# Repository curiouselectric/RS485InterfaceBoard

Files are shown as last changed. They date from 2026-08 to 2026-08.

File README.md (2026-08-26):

# RS485 Sensor Interface Board

A unit to interface various RS485 sensors with a simple serial interface via an ATMega328-based circuit. The unit also provides averaged data, controlled stepped-up supply voltage and a field-adjustable ID.

"Why do you need that?", you ask.... 

I had been wanting to use an industrial soil mositure sensor for a simple project. This device was only available as an RS3485 device. So I ordered that - it then took days of head scratching to sort basic communication with the device. This unit is meant to simplify reading of avaeraged data from RS485 sensors and make it easy to get that data into your project via a simple serial request/reply set of commands.

The other issue with a lot of the RS485 sensor is that they need higher voltages supplied (such as 12V or even 24V DC). So on this interface board I added a DC-DC step up converter to power the sensor. 

I was also concerned with energy consumption (my project was battery based). If I was to leave the DC-DC converter running all the time then my battery would run down very quickly. So I added control of the power to the sensor, so that I can power up, take the readings then power down. This saves a huge ammount of energy (well, proportional to my battery size).

## Overview

The problem with measuring sensors with values that change relatively quickly is that they constantly need to be checked. This requires a bit of microcontroller time and processing. This unit is designed to solve that.

Wire up your RS485 sensor. Power the unit up. Then it will save the averaged data for you. You can then get hold of the data through serial requests and process as you need.

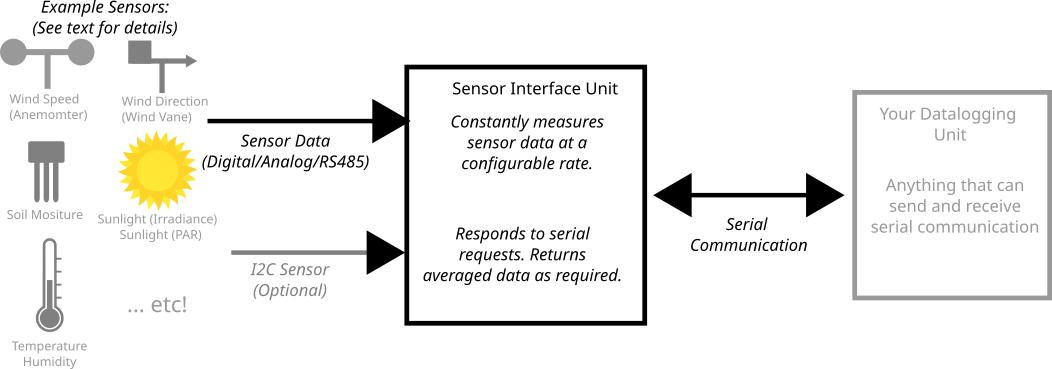
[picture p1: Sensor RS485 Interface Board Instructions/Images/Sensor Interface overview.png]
Overview


I wrote this to interface to an ESP32 data logger, which sleeps most of the time. It wakes up, talks to the RS485 sensor, gets the data it needs, then goes back to sleep, knowing the RS485 Interface Board is always monitoring.

It was designed as a relatively simple interface to remove the need for monitoring pulses/dealing with RS485 requests/getting sensor data and averaging the sensor data.

The brilliant [ESPHome project](https://esphome.io/components/#environmental) has loads of sensor types you can interafce easily with a low cost ESP microcontrollers. For systems that have WiFi and good power connections then that project is a good resource to use. This project is designed for very low power systems (battery based datalogging) and for situations where easy access to Wi-Fi is not available.

# RS485 Sensor Interface Firmware

The firmware for this project has been moved to: 

[https://github.com/curiouselectric/SensorInterfaceBoard/tree/main/Sensor%20Interface%20Board%20Firmware](https://github.com/curiouselectric/SensorInterfaceBoard/tree/main/Sensor%20Interface%20Board%20Firmware)

This is within the Sensor Interface Board repository: [https://github.com/curiouselectric/SensorInterfaceBoard](https://github.com/curiouselectric/SensorInterfaceBoard)

I have done this to keep all the sensor boards up to date with just one set of firmware for all the sensor boards.

# Hardware

A number of PCBs have been designed in KiCAD. This repository holds the RS485 sensor and is available here. A small PCB has been designed.

There is one reset switch, one user input switch and one LED output. 

There is a step-up DC-DC converter with power control (to power higher voltage sensors). 

There is a TTL to RS485 converter (to connect to the RS485 sensors)

There is a 4 pin 'Grove'-type connector for direct connection I2C (code for this is not yet implemented) 

## Board ID Number

Each unit can have a unique ID (using a push link 6 pin pad for 0-7 values), so multiple units can be added to a serial bus, if needed. The defalt is 0 (no links used).

## PCB User Switch and User LED

There is one user switch and one user LED on the unit.

The LED will show a regular flash every 5 seconds. This will briefly flash once every 5 seconds if the unit is in 'Response' mode. The LED will briefly flash twice every 5 seconds if the unit is in 'Broadcast' mode. Data will be sent at the broadcast rate.

The LED will also flash whenever data is sent of the serial port. The LED will go on before data sent and then off after data is sent.

Pressing the user switch for >0.5 seconds and then releasing will result in a switch press.

A switch press will increment the mode from 0-1-2-3-4-5 then back to 0.

The unit will flash after a button press to indicate the broadcast mode (so 0 flashes if the value is 0, 1 flash if the value is 1 etc).

If this is set to 5 then the unit works in 'Response' mode.

If this is set to 0-4 then the unit is in 'Broadcast' mode and will send the data at the relevant interval (0 = 1s, 1 = 10s, 2 = 1 min, 3 = 10 min and 4 = 1 hour).

The mode can also be set with a serial request, using the "Set the unit to broadcast:" method (see below).

# Serial Data and Commands

It returns the average values and information when requested on serial port.

If the 8-bit CRC (Cyclic Redundancy Check) is used then each request must have a 2 char CRC added between the ? and # within these commands (labelled ^^ here).
For the responses, if no CRC enabled then the ?^^ within these commands is NOT returned. You must use the ? for a command, but the response will not contain it.

At all other times then the unit is asleep.

## Set the unit to broadcast:

Request: "aaI0SEND*?^^#" where * is an int (0)= 1s data, (1)= 10s data, (2)= 60s/1 min data, (3)= 600s/10 min data, (4)= 3600s/1hr data, (5)= NO data

Returns: "aaI0SEND*?^^#" + CRC if requested where * is an int (0)= 1s data, (1)= 10s data, (2)= 60s/1 min data, (3)= 600s/10 min data, (4)= 3600s/1hr data, (5)= NO data

You can also set the unit to broadcast using the user switch. Press the button for around 0.5s or more then release. This will go through the boradcast modes from 0-1-2-3-4-5 then back round to 0. The LED will flash the number of times for the setting (so send = 0 the unit will not flash, but data will appear within 1 second!).

If the unit is in broadcast mode then the minimum and maximum wind speeds and the wind vane data are all reset each time period.

## What is baud rate?:

Request: "aaI0STBD?#" ("aaI0BD?dc#" with CRC)

Returns: "aI0CHBD9600?^^#"  // Where 9600 is the baud rate 

## Set Baud Rate:

Request: "aaI0STBD\*?^^#"  Where \* is (0)1200, (1)2400, (2)9600, (3)57600, (4)115200

Returns: "aaI0BD9600?^^#"   // Where 9600 is the baud rate + CRC if requested

## What is ID?:

Mentioned at start up of unit - it is hardware set... and cannot be changed in code.

ID selection is by using a shorting link on the pads labelled 1, 2 and 4. The default is for no pads to be connected and the ID is 0. This means the unit will respond to "I0" as the ID.

To change the ID to another number from 0-7 then use a shorting link on the pins to create a binay number. The connections are:

1    |2    |4     | ID
-------|-------|-------|----
NC     |NC     |NC     | 0
CONN |NC     |NC     | 1
NC     |CONN |NC     | 2
CONN |CONN |NC     | 3
NC     |NC     |CONN | 4
CONN |NC     |CONN | 5
NC     |CONN |CONN | 6
CONN |CONN |CONN | 7

You can request the ID:

Request: "aaI*ID?^^#"  The * value can be anything.

Returns: "aaIXID:X?^^#"   // Where X is the device ID + CRC if requested

## Request Data from ONE channel

Request: “aaI0R00A*?^^#” where 00 is the channel number (00, 01 etc) and * is the averaging period (* = 0 for 1 sec data, 1 for 10 sec data, 2 for 60 sec (1 min) data, 3 for 600 sec (10 min) data and 4 for 3600 sec (1 hr) data 

Returns:  "aaI0R00A*:123.40:123.40:123.40?^^#"  // This wil return the average data then : then the minimum value then : then the maxximum value.

## Request Data from ALL channels

Request: “aaI0RAAA3?^^#”

Returns: "aaI0RAAA1:123.40:567.80?^^#" where the first item of data is channel 0, the next is channel 1. This will depend upon the number of channels.

## Request ALL Minimum data

Request: “aaI0RMNA4?^^#”  - does not matter what averaging period. min/max are just the min/max seen at max data rate.

Returns: "aaI0RMN:123.40:567.80?^^#"  where the first item of data is channel 0, the next is channel 1. This will depend upon the number of channels.

## Request ALL Maximum data

Request: “aaI0RMXA0?^^#”  - does not matter what averaging period. min/max are just the min/max seen at max data rate.

Returns: "aaI0RMX:123.40:567.80?^^#"  where the first item of data is channel 0, the next is channel 1. This will depend upon the number of channels.

## Reset the Min and Max value:

The min and max of each channel are logged. These are reset if the data is sent in broadcast mode. If the unit is in Response mode then you need to reset the min/max when you have taken the data.

Request: "aaI0RESET?#" ("aaI0RESET?d9#" with CRC)

Returns: "aaI0RSTOK#"

## Request Temperature, Humidity and Pressure Data

This command can only be used if the I2C AHT20/BMP280 sensor is attached and has been defined in the code. Otherwise it will return an error.

You can call this at any time and the unit will request from the sensor. It is NOT averaged or requested at any other point.

The Temp and Humidity board is an AHT20 (with device ID 0x38) and a BMP280 is used to measure the air pressure (with device ID 0x77).

Request: "aaI0TEMP?^^#"  (^^ for the CRC)

Returns: "aaI0T$$.$$H$$.$P$$$$$$?^^#" (^^ for the CRC) and $$$ are the values (floats) for Temeprature in C and Reltive Humidity in % and Air Pressure in Pa.
Returns: "aaI0T-H-P-#" if the board is not connected or there is an issue wth one of the sensors.

## Serial 'Button' press

You can simulate a button press with a serial command. This might be useful for some logging applications

The command "aaI0SWA?^^#"  (Where ^^ is the CRC of the data before the ?) will act just like a button press. This is for control via a data logger serial port without access to the physical switch.

Request: "aaI0SWA?^^#" 

Returns: "aaSEND*?^^#", where * is the time interval to send data (0->1->2->3->4->5->0 etc, with 5 never sending)

## What is the software version?:

Request: "aaI0SWV?^^#"

Returns: "aaI0SWV:1.0?^^#" (where 1.0 is the software version)

## What is the device type?:

Request: "aaI0DT?^^#""

Returns: "aaI0DT:SM?^^#" where SM is the device type (SM = Soil Moisture) - check the sensor list for these 2 char codes.

## Add CRC check:

Within the config of the firmware a CRC (Cyclic Redundancy Check) can be added to the data (or not!).

Set this true using the flag in the config.h file:

  #define ADD\_CRC\_CHECK     true    // Use this to add CRC check to incomming and outgoing messages
  
This uses the CRC routines from Rob Tillaart, available here: https://github.com/RobTillaart/CRC

A 'CRC-8/SMBUS' is perfromed on the data and a 2 byte CRC code is added to all replys (and expected on all enquiries). This is added between a ? and # symbol.

If no CRC then the end char is a #.

For example: aaI0RESET?d9# has the CRC check d9 added to the reset request.

Remember: Capitalisation will affect the results: D is not the same as d!

You can use this online calculator to check your CRC: https://crccalc.com/ The type of CRC is CRC-8/SMBUS.

## Failure codes:

If data is not that length or does not have 'aa' and '#' at start/end then return with send "aaFAIL\*\*#" error code. All will have CRC on these codes, if requested.

+  "aaFAILCRC?^^#": CRC check fail
+  "aaFAILTL?^^#": String too long
+  "aaFAILID?^^#": Problem with ID
+  "aaFAILIDX?^^#": ID not correct to device
+  "aaFAILPE?^^#": No aa and # on the string
+  "aaFAILBD?^^#": Baud rate change fail
+  "aaFAILCN?^^#": Channel number requested is greater than channels existing
+  "aaFAILCMD?^^#": Command not recognised 

# Sensor Specific Commands
For each sensor type there are additional commands. These are only available if the correct firmware has been installed.
They are listed here.

## 'SM' RS485 Soil Moisture Sensor

There are no extra commands.
Soil Moisture (% (m3 water in m3 soil)) and Soil Temperature (C) are monitored.

## 'PY' RS485 Pyranometer Irradiance Sensor

There are no extra commands.
Irradiance (in W/m2) is monitored.

## 'DC' RS485 DC Power Sensor

There are no extra commands.
Voltage (V), Current (A), Power (W) and cumulative Energy (Wh) are monitored.

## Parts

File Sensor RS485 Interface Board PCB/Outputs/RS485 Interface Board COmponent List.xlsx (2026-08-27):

Id | Designator | Footprint | Quantity | Designation | Supplier and ref | Column1 | _1
1 | C1, C3, C4 | C1_wide_lg_pad_2 | 3 | 100n
2 | C2 | C_Radial_D6.3_L11.2_P2.5 | 1 | 100u
3 | C5, C6 | C1_lg_pad | 2 | 22p
4 | D1 | TH_LED-5MM_AK | 1 | LED
5 | DCDC1 | TH_DCDC_Step_up_MT3608 | 1 | DC-DC_GENERIC
6 | J1 | SIL-3_lg_pad_PWR_SELECT | 1 | PWR SEL
7 | P1 | SIL-4_Grove_SCREW | 1 | SERIAL
8 | P2 | RS485 Logo Design | 1 | LOGO2
9 | P3 | PCB_outline_JSL22L | 1 | PCB
10 | P5 | SIL-4_Grove_Labelled_Correct | 1 | I2C
11 | P6 | SIL-4_Grove_SCREW | 1 | RS485
12 | P7 | ID_SELECT_3x2 | 1 | BOARD ID
13 | P8 | TH_6x1_FTDI | 1 | PROG
14 | P9 | ISP_3x2 | 1 | ISP
15 | P10 | TCEC_Words_13mm | 1 | LOGO3
16 | P11 | 2019_011_16_CuriousElectricCompany_Logo_Round_Logo_No_words_KiCAD_10mm_PCBLogo | 1 | LOGO2
17 | Q1 | TO-92_Inline | 1 | 2N3904
18 | Q2 | TO-251-3_Vertical | 1 | IRFR9220
19 | R1 | TH_Resistor_1 | 1 | 1k
20 | R2, R3 | TH_Resistor_1 | 2 | 100k
21 | R4 | TH_Resistor_1 | 1 | 470
22 | R5 | TH_Resistor_1 | 1 | 10k
23 | R6, R7 | TH_Resistor_1 | 2 | 4k7
24 | SW1 | TH_FRONT_SW | 1 | SWA
25 | SW2 | TH_FRONT_SW | 1 | RST
26 | U1 | TH_RS485_BI_SERIAL | 1 | RS485_TTL_Module
27 | U2 | DIP-28_W7.62mm | 1 | ATmega328P-P
28 | Y1 | Crystal_HC49-4H_Vertical | 1 | 8MHz_XTAL

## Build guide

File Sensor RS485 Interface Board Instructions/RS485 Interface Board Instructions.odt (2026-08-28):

| RS485 Sensor Interface Board Kit Instructions

Date: | 26/8/2026 | Version: | 1.0 | By: | Matt Little

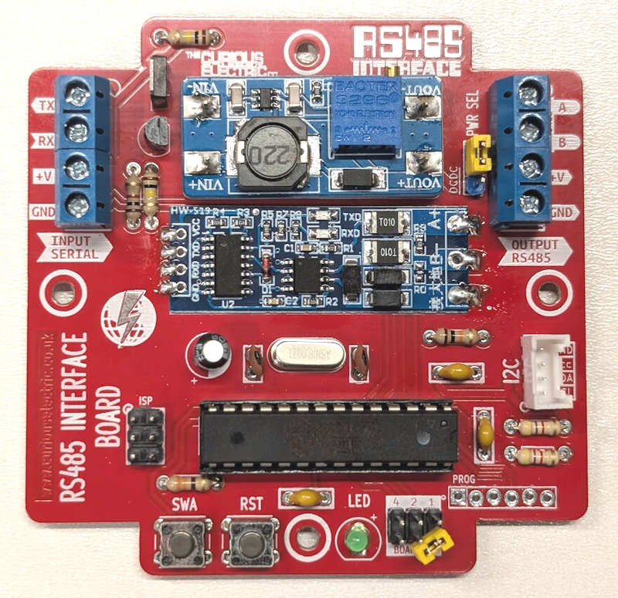
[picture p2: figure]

This circuit adds an RS485 interface to an ATMEGA328 to connect to different RS485 sensors and provide averaged data via a UART interface. It is designed to be easy to use, provide correct voltage levels and be energy efficient.

Note: It requires another micro-controller unit to request and store the data from the sensor interface board.

You must upload the correct firmware for your sensor, please check the github for examples:

https://github.com/curiouselectric/SensorInterfaceBoard

It provides a more easy to use UART serial interface to obtain averaged data the sensor. Data can be 1s,10s, 1min, 10min and 1hr averaged data along with the maximum and minimum values within that time period.

It also provides a controlled step-up converter (if needed) to power the attached sensor, which can step up the supply voltage (3.3V or 5V DC) to the voltage required by the sensor, such as 12V or 24V. This can be switched off between sensor reads to save energy from the battery.

There is also an I2C interface to add additional sensors, such as a temperature or humidity.

# Parts included:

| 1 x Grove socket | 2 x 2 way headers 1 x 3 way header | 2 x 3x2 Header Pins | | 2 x Jumpers | | IFRF9220

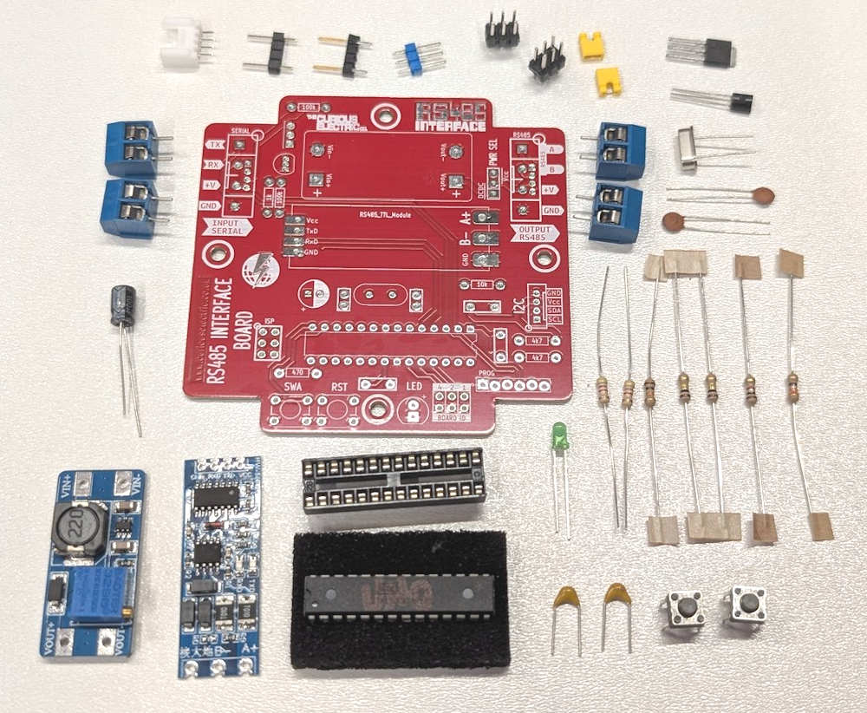
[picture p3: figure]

| | | | | | | 2N3904
| | | | | | | 16MHz crystal
2 x 2 way screw terminals | | | | | | | 2 x 2 way screw terminals
| | | | | | | 2 x 22pf Capacitor
100uf Capacitor
PCB | | | | | | | 7 x Resistors
DC-DC Converter | RS485-TTL Module | ATMEGA328 and IC holder | | 3 x 100nf Capacitor (2 shown!) | | LED | 2 x Switches

# Parts list:

Item | Ref | Quantity | Item | Ref | Quantity
PCB | | 1 | Resistor - 1k | R1 | 1
Capacitor – 100nf | C1, C3, C4 | 3 | Resistor - 100k | R2, R3 | 2
Capacitor – 100uf | C2 | 1 | Resistor - 470 | R4 | 1
Capacitor – 22pf | C5, C6 | 2 | Resistor - 10k | R5 | 1
Green LED | D1 | 1 | Resistor - 4k7 | R6, R7 | 2
DC-DC Converter | DCDC1 | 1 | Tactile switch | SW1, SW2 | 2
3 Way Header | J1 | 1 | RS485 – TTL Module | U1 | 1
Grove connector 4 pin | P5 | 1 | Modified 4 way headers with 2 pins | For U1 | 2
2 Way Screw Connector (2 for each) | P1, P6 | 4 | 28 Pin IC DIP Holder | U2 | 1
3x2 Header | P7, P9 | 2 | ATMEGA328P 28pin | For U2 | 1
Transistor – NPN, 2N3904 | Q1 | 1 | 16MHz Crystal | Y1 | 1
Transistor – N-FET, IFRF9220 | Q2 | 1 | Jumpers | | 2

# Tools required (not supplied):

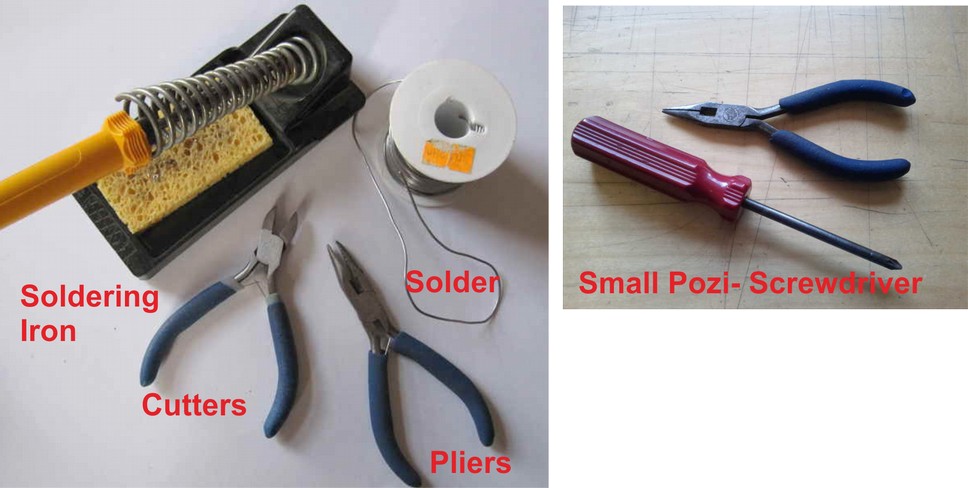
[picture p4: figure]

| | Long-nosed Pliers
Soldering Iron | | Posi-drive and flat-head Screwdriver
Solder
Side cutters

Additional Items

- USB to 6 way ‘FTDI’ style serial converter:
  - Search for “FT232RL USB to TTL Mini USB Port FTDI Serial Adapter Module for Arduino 5V/3.3V” on eBay
  - Or this FTDI 3.3V one: https://ftdichip.com/products/ttl-232r-3v3/
  - Or this FTDI 5V one: https://ftdichip.com/products/ttl-232r-5v/
  - You can also use an Arduino as a USB to serial converter.
- To update/change code:
  - Computer with Arduino IDE and additional libraries installed. (See github repository for the Sensor Interface Software for more details: https://github.com/curiouselectric/SensorInterfaceFirmware ).

# Device & Wiring Overview:

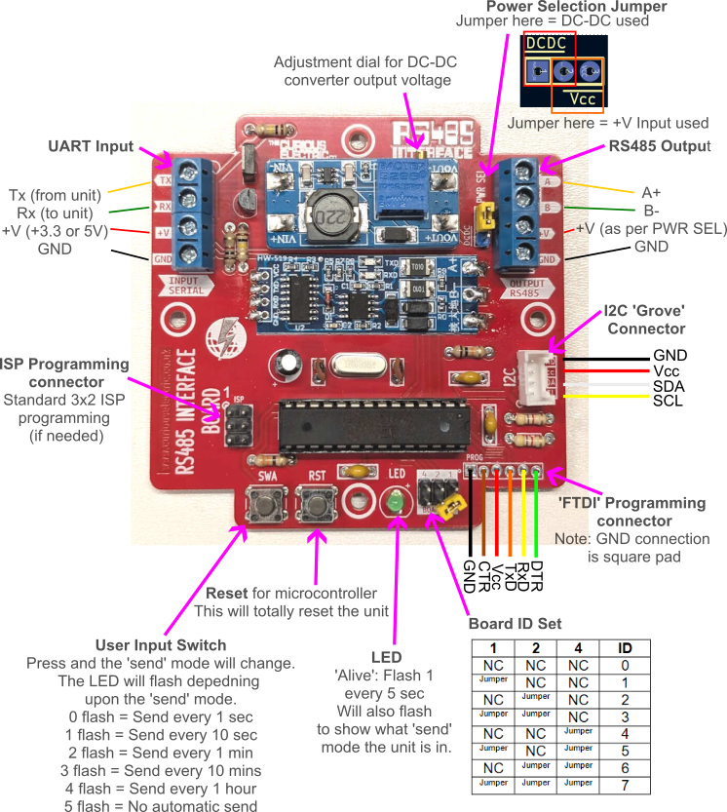
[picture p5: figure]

Instructions:

Step: 1 | Add resistors

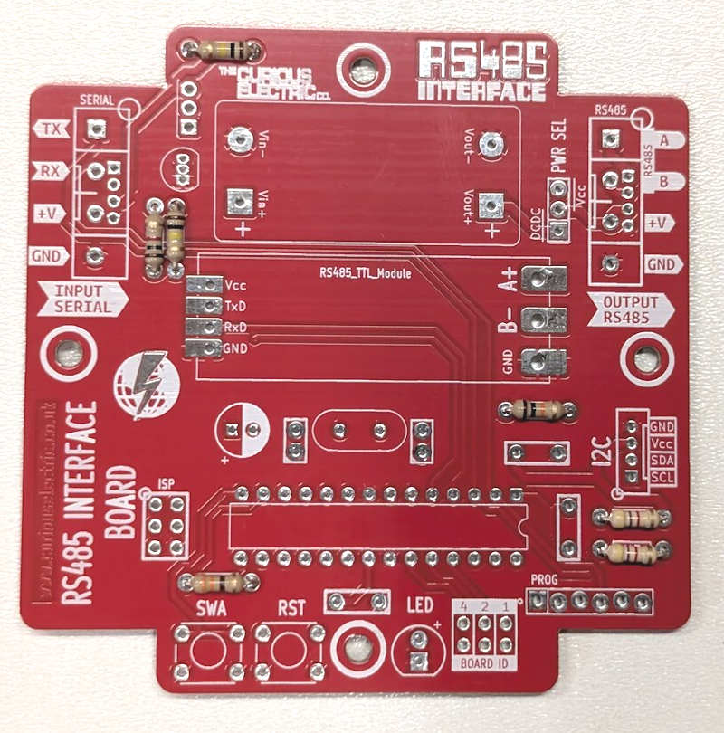
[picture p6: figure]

| | Value Ref Colour 1k R1 Brown, Black, Red, Gold 100k R2, R3 Brown, Black, Yellow, Gold 470 R4 Yellow, Violet, Brown, Gold 10k R5 Brown, Black, Orange, Gold 4k7 R6, R7 Yellow, Violet, Red, Gold Insert and solder the resistors. Polarity does not matter for resistors. Ensure they are soldered flat close to the PCB. Use a multimeter or colour code chart to ensure correct resistor values.

Step: 2 | Add capacitors

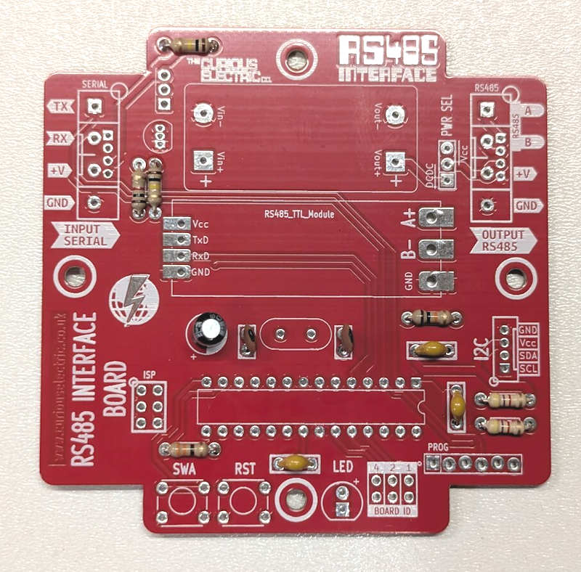
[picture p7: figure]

| | First solder the non-polarised capacitors. Orientation of these does not matter: Value Ref Marking 100nf C1, C3, C4 104 (brown blob) 22pf C5, C6 22(orange disk) Next solder the polarised capacitor. Ensure correct orientation of this component. The negative lead is marked with a white strip. The positive lead is slightly longer than the negative. Align the positive lead with the + sign and the negative lead with the white PCB marking. Value Ref Marking 100uf C2 16V 100uf

Step: 3 | Add IC holder and crystal

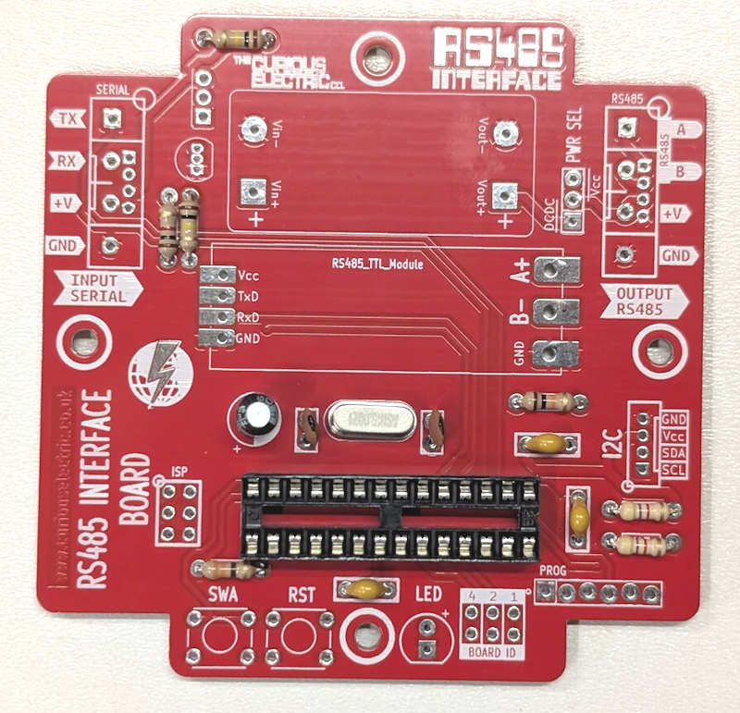
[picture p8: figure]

| | A 28-pin IC holder fits into U2 Ensure correct orientation! Ensure the notch on the holder aligns with the notch shown on the PCB. The silver crystal is soldered into the area marked Y1. Orientation does not matter.

Step: 4 | Add Switches and LED

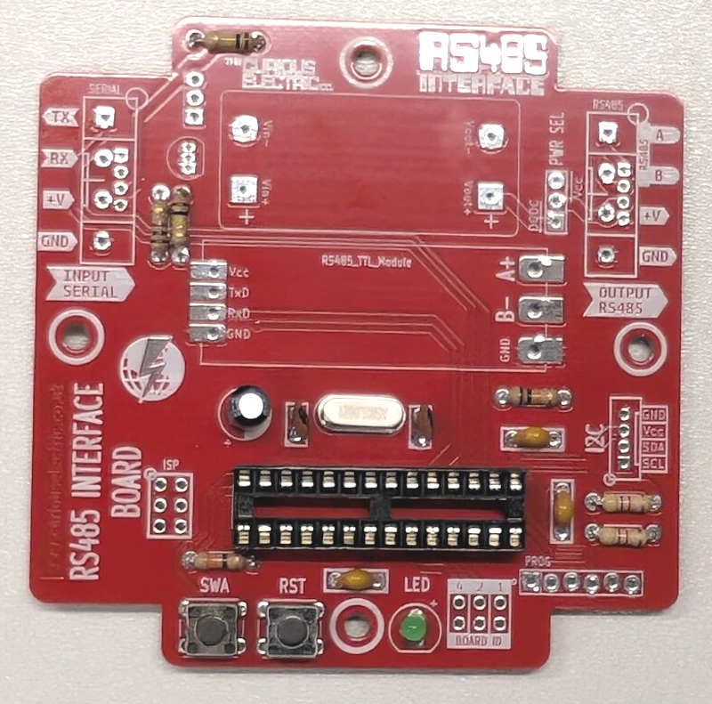
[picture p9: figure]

| | Solder the two push switches into the areas marked SW1 (“SWA”) and SW2 (“RST”). They can only fit in the correct orientation. Ensure correct orientation for the LED, D1. Solder the LED into D1. The long lead is positive, so place that into the hole marked +. The negative side is slightly flat.

Step: 5 | Add transistors

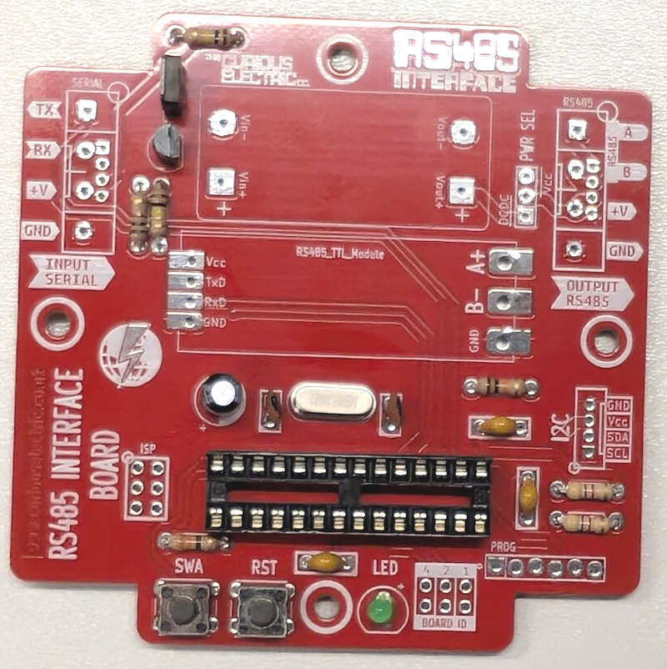
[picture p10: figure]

| | Solder transistors Q1 and Q2 into the correct locations. Ensure both transistors follow the markings on the PCB. There is a thicker white line showing which side the heat-sink on transistor Q2 should be aligned with.

Step: 6 | Add header pins and set ID

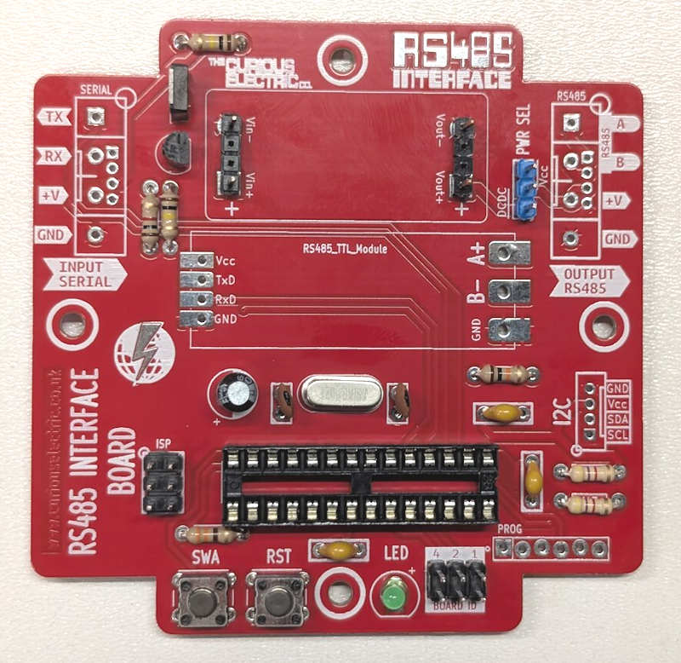
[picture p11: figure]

Use the 2 x special 2 pin headers and solder onto the pads for the DC-DC converter (DCDC1)

Use the 3x1 header pins for the “PWR SEL” area (J1). A jumper on this controls if either the sensor is powered by the supplied voltage (on the input serial terminal) OR the DC-DC converter.

Use the 2 x 3x2 header pins and put them into the areas marked P7 and P9.

P9 is an ISP (In Series Programmer) connector for uploading code onto the unit (if needed)

P7 is used to set the board ID.

You can set the ID of the unit by connecting the header pads with a jumper. The default ID is 0, with no jumper attached.

1 | 2 | 4 | ID
NC | NC | NC | 0
Jumper | NC | NC | 1
NC | Jumper | NC | 2
Jumper | Jumper | NC | 3
NC | NC | Jumper | 4
Jumper | NC | Jumper | 5
NC | Jumper | Jumper | 6
Jumper | Jumper | Jumper | 7

Step: 7 | Add RS485 module board

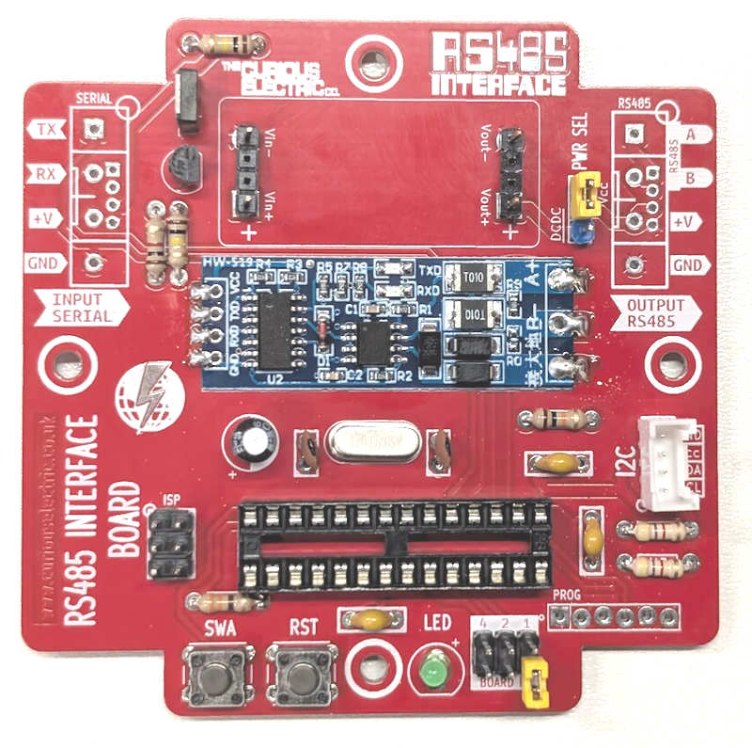
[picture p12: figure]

| | Place the RS485-TTL module flat onto the circuit board. Ensure the pads align with the castellated holes on the module board. Add a blob of solder to each of the pads (4 smaller ones on the TTL side and 3 larger ones on the RS485 side). Ensure there is enough solder to make a good connection.

Step: 8 | Add DC-DC converter module

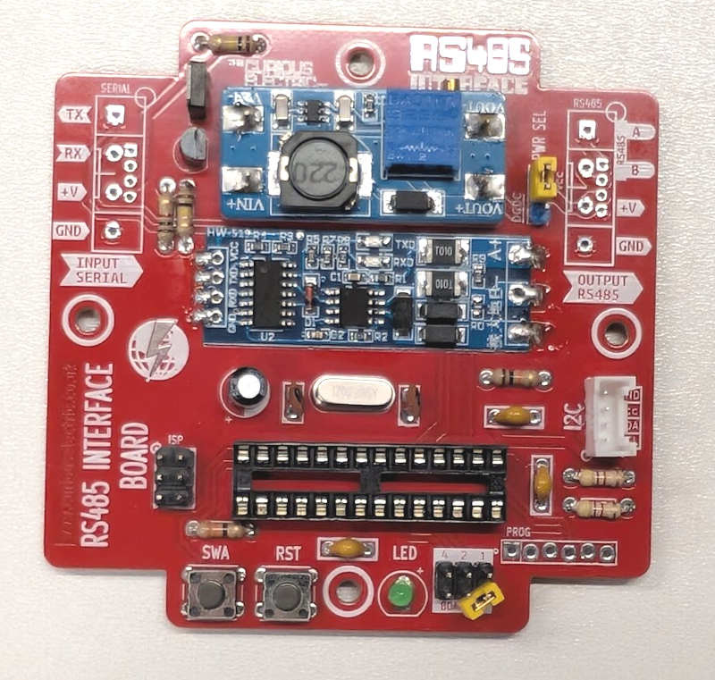
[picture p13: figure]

| | Fit the DC-DC converter module onto the header pins you soldered in step 6. Make sure this is put on the right way around. The flat side of the module should go against the main red PCB. Make sure the little brass adjustment dial is pointing to the edge of the PCB. This can be adjusted with a small flat screwdriver. It can be adjusted from 3.3V up to 30V DC. The max current is 2A, but it is advised to stay under 500mA at most. Note: Before adding your sensor you must check the output voltage is correct for your RS485 sensor. See details later in these instructions.

Step: 9 | Add screw terminals and Grove connector

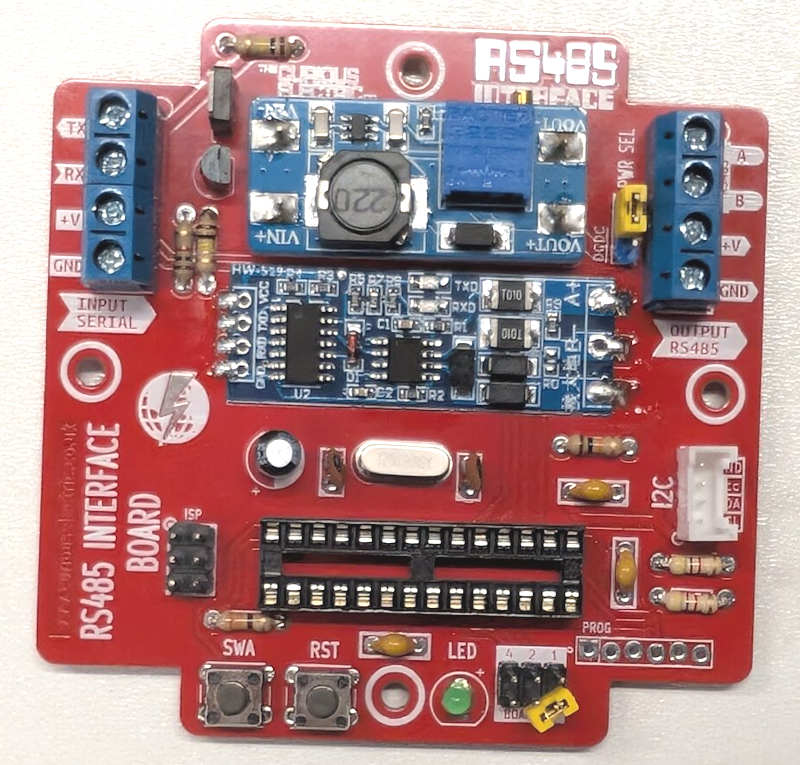
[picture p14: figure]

| | Use two of the 2-way screw terminals and slot them together to make a 4 way screw terminal unit. Do this with the two sets of 2-way screw terminals. Solder them into the areas for the INPUT (P1) and the RS485 OUTPUT (P6). Ensure the holes for the cables are face out, so cables can enter from each side. Also solder the ‘Grove’ 4 pin connector into P5. Ensure you fit this as shown, with the large notch facing to the edge of the PCB.

Step: 10 | Add microcontroller
| | You can now carefully insert the ATMEGA328 microcontroller into the IC holder. Ensure the notch on the IC matches the IC holder and the PCB! Be careful no pins are bent as you push this component in.

Step: 11 | PCB is finished!
Have a nice cup of tea.

Step: 12 | Check Device: Connect to USB-TTL Converter

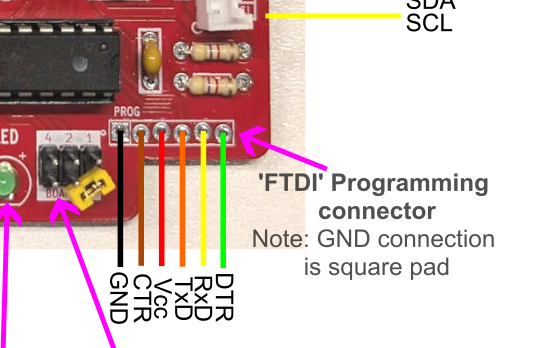
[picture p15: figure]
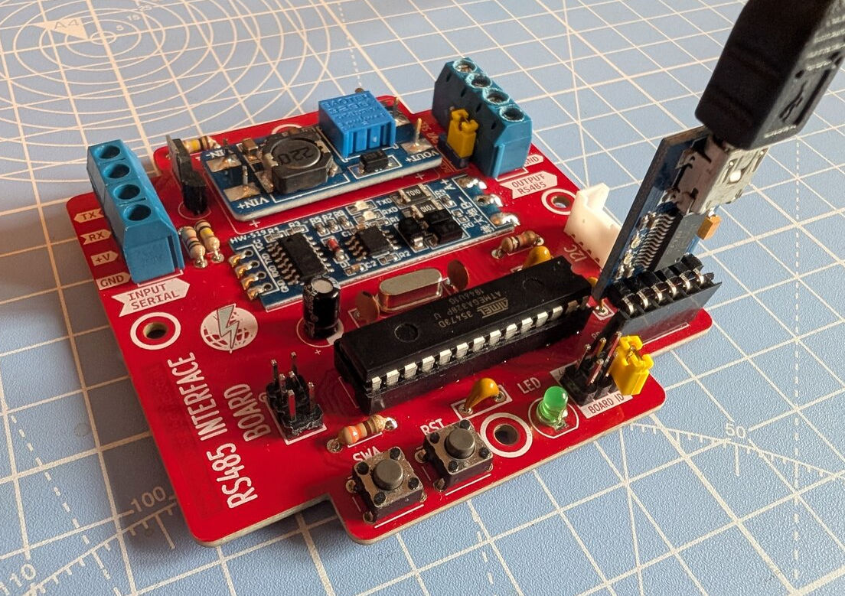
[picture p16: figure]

To program and check the microcontroller then you will need a USB to TTL converter with the ‘FTDI’ pin out. This fits into the ‘PROG’ connector. This will also power the board. You can also use a USB-TTL converter cable wired to the SERIAL INPUT terminals, but you will not be able to upload new code via that connector. If you monitor the serial port at 9600 baud then you can send and receive responses. Check that some data is being received and that the green light flashes to show the unit is working.

Step: 13 | Check DC-DC converter voltage

BEFORE you add the RS485 sensor test and double check the output voltage on the DC-DC converter.

Power up the device, either from the PROG connection OR from the “INPUT SERIAL” connections.

This will depend upon the ‘PWR SEL’ jumper, which chooses if the Serial Input +V voltage is used OR if the DC-DC converter is used.

If the DC-DC converter is used then check the output voltage with a multimeter. The voltage may jump as the power is switched, the higher voltage will be the ‘blip’ of output voltage for the sensor. This switches on and off to save energy.

This should be the same as required by your RS485 sensor.

Turn the little brass dial with a preset trimmer or small screwdriver.

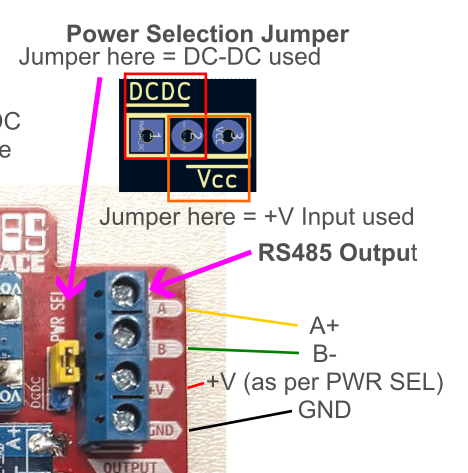
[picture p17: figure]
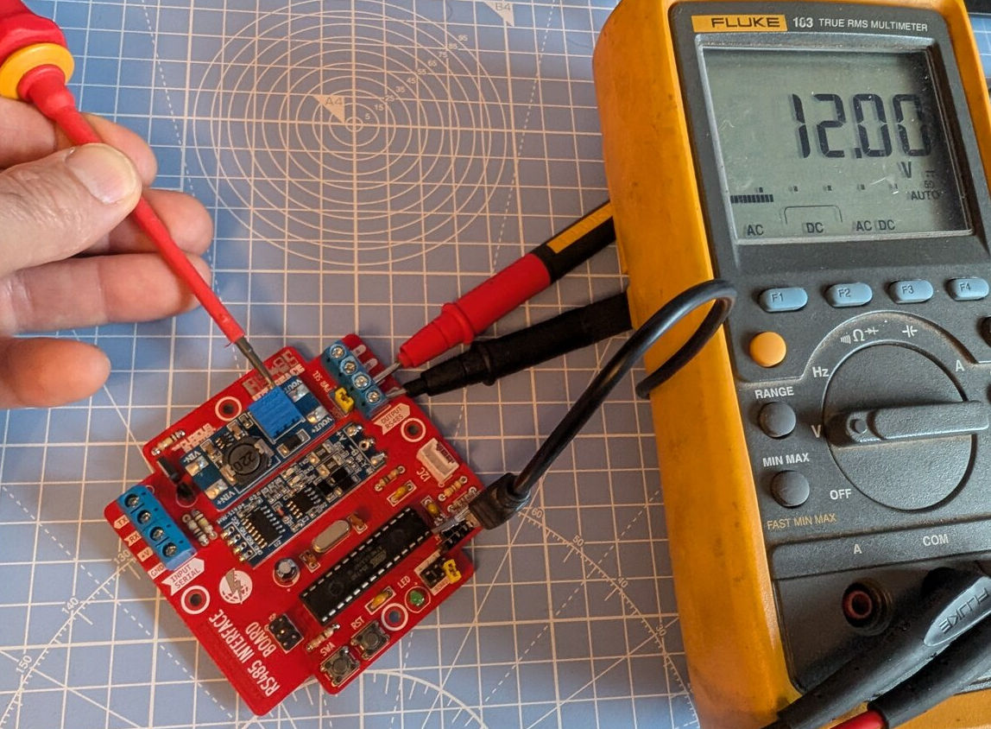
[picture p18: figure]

Step: 14 | Wire up RS485 Sensor

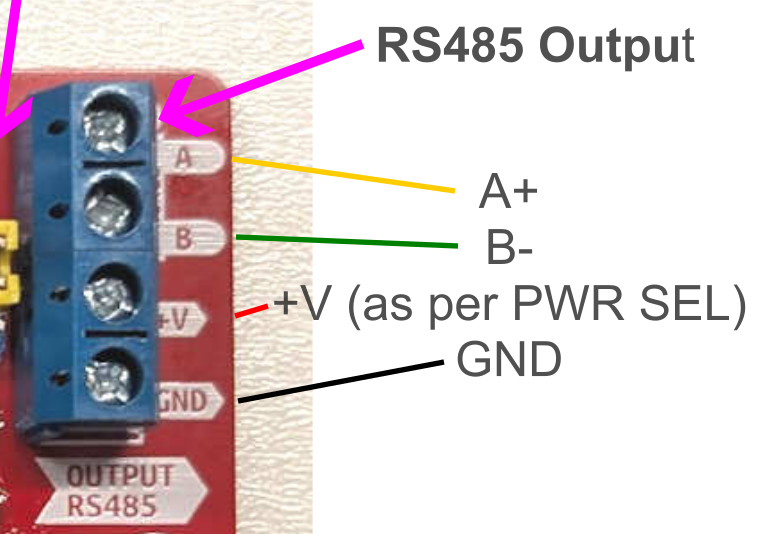
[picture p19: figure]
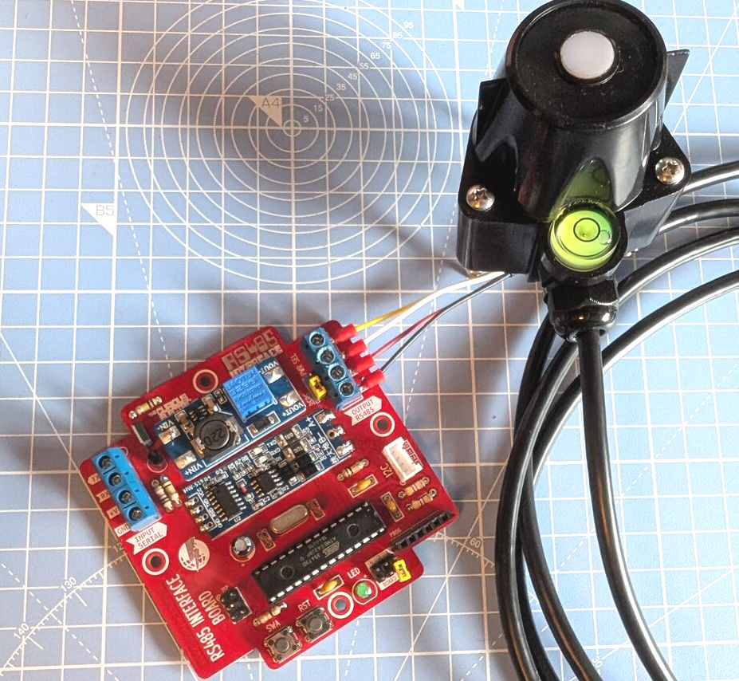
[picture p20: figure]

Now the output voltage has been set you can wire up the RS485 sensor you are using. Switch off power to the board. Wire up your sensor to the “OUTPUT RS485” terminals following the screen printed labels. In the photo shown here, a solar pyranometer has been wired up. Check your sensor data-sheet for the correct colour wires and pin out, as it may not be the same as shown here.

Step: 15 | Wire up the Serial Input to your microcontroller.

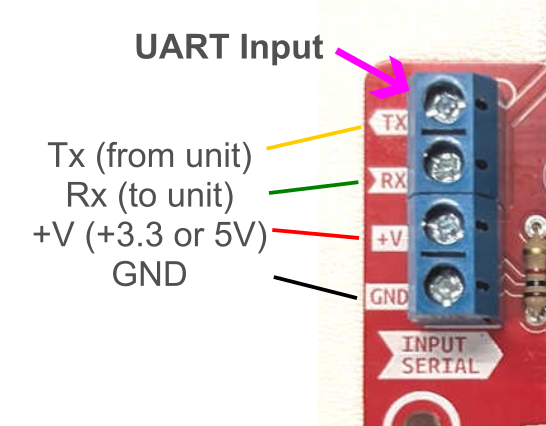
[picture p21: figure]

There is one main ‘Input Serial’ connector (sometimes called UART Input). Wire this up to your microcontroller or to a USB-TTL converter cable. Double check that Rx and Tx are correctly wired (usually Rx from the microcontroller goes to Tx of the sensor and vice-versa). Check you are getting data via the Input Serial connections.

Step: 16 | Program Device: Connect to USB-TTL Converter
Note: This step is only needed if firmware not already uploaded. To program the microcontroller then you will need a USB to TTL converter with the ‘FTDI’ pin out. If you monitor the serial port at 9600 baud then you can send and receive responses. You can also upload new firmware using the Arduino IDE. These units use the ‘MiniCore’ board manager and the IC is the “ATMEGA328” with an “External 16MHz” oscillator. Follow the github examples and information for the most up to date information regarding the serial data and the functionality of the unit.

Step: 17 | Ensure the firmware used on the unit is the correct version for your sensor!
Different firmware options are required for different RS485 sensors. This can be where the fun begins! You can alter the code and improve it as you need. Note: This step is only needed if the correct firmware has not already been uploaded. For options and firmware upload options, please see: https://github.com/curiouselectric/SensorInterfaceBoard This is kept online, so it can be easily updated.

Step: 18 | Send Serial Commands

There are many serial commands that the unit can respond to.

In normal operation the unit will start up and the LED will flash every 5 seconds to show it is alive.

If you monitor the serial port data you should see data at 1 or 10 second intervals at 9600 baud rate. This depends upon the send rate selected. Press SWA and this will roll through the 6 data send rates (which are 1second, 10 second, 60 second, 10 min, 1 hour and “no data send”). Put it into 1 second data mode and you should see data appearing every second. Check the data looks correct.

For the most recent information, please see:

https://github.com/curiouselectric/SensorInterfaceBoard

This is kept online, so it can be easily updated.

Step: 19 | Write your own code
Everyone’s application is different, so this is where things get fun for your application! You need to think about what you would like from the unit. I have set up units that send out data at regular 1 min outputs with a wireless transmitter. This used broadcast mode. I have also set up units that record the data to an SD card by using request mode.

## Design Files:

The design files for this PCB, along with these instructions, is available from the github repository for this board:

https://github.com/curiouselectric/RS485InterfaceBoard

Note: This repository is just for the design files, not the firmware. Please see links in instructions for the firmware repository.

## Contact details:

This kit has been designed and produced by:

The Curious Electric Company

hello@curiouselectric.co.uk

www.curiouselectric.co.uk

We would like you to be happy with this kit. If you are not happy for any reason, then please contact us and we will help to sort it out.

Please email hello@curiouselectric.co.uk with any questions or comments.

Please tweet us at @curiouselectric

If any parts are missing from your kit, then please email hello@curiouselectric.co.uk with details, including when and where the kit was purchased.

More technical information can be found via www.curiouselectric.co.uk

# Circuit Schematic Page 1:

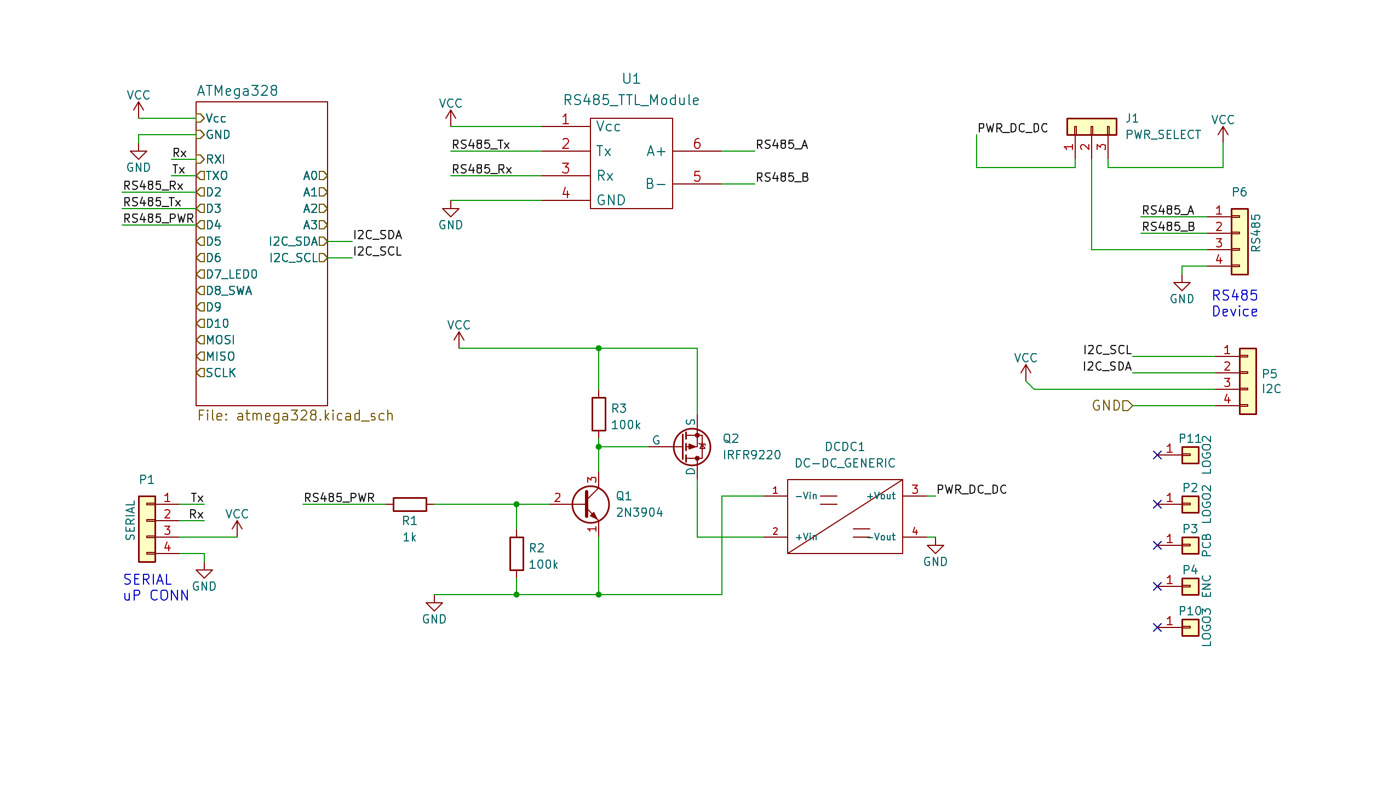
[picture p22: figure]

# Circuit Schematic Page 2:

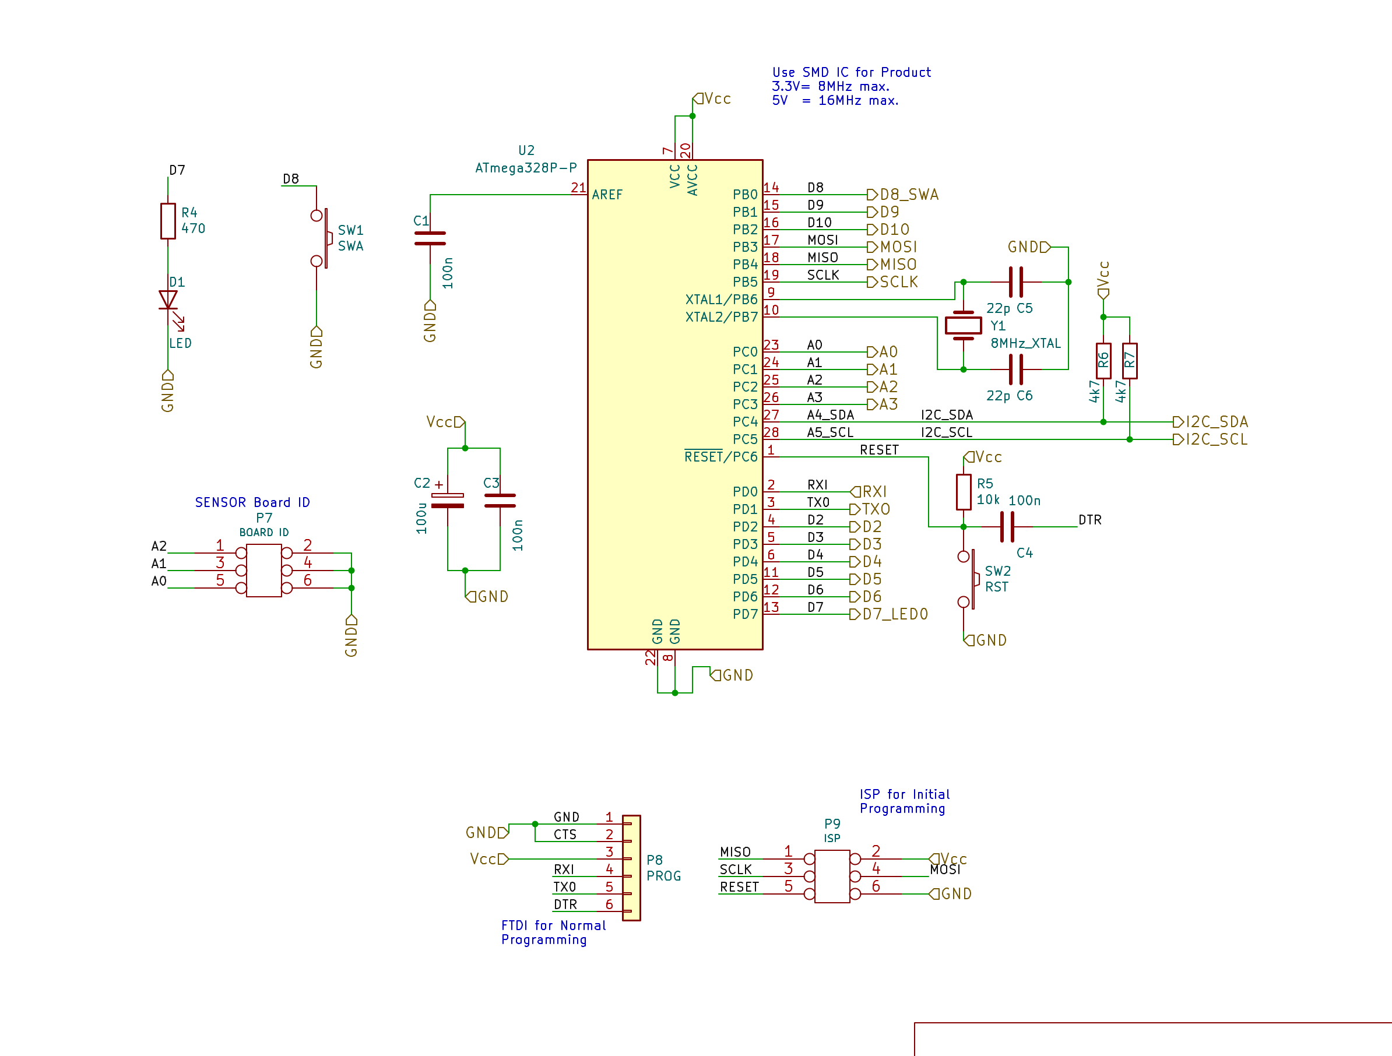
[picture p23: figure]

# PCB Design:

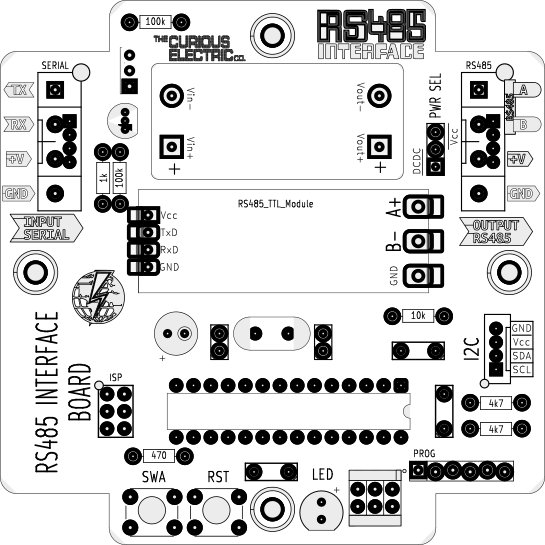
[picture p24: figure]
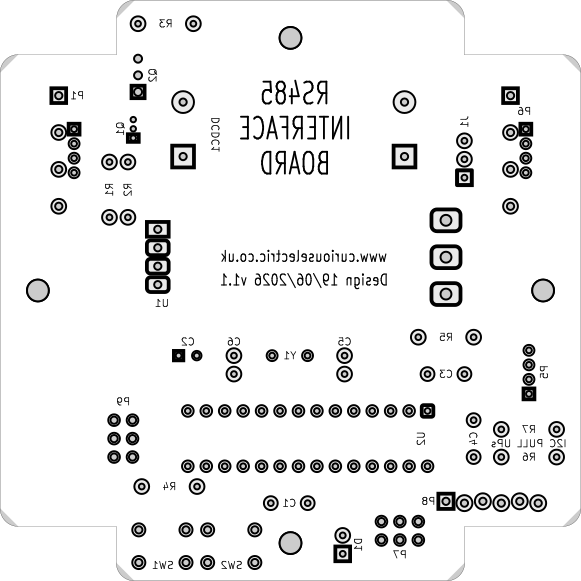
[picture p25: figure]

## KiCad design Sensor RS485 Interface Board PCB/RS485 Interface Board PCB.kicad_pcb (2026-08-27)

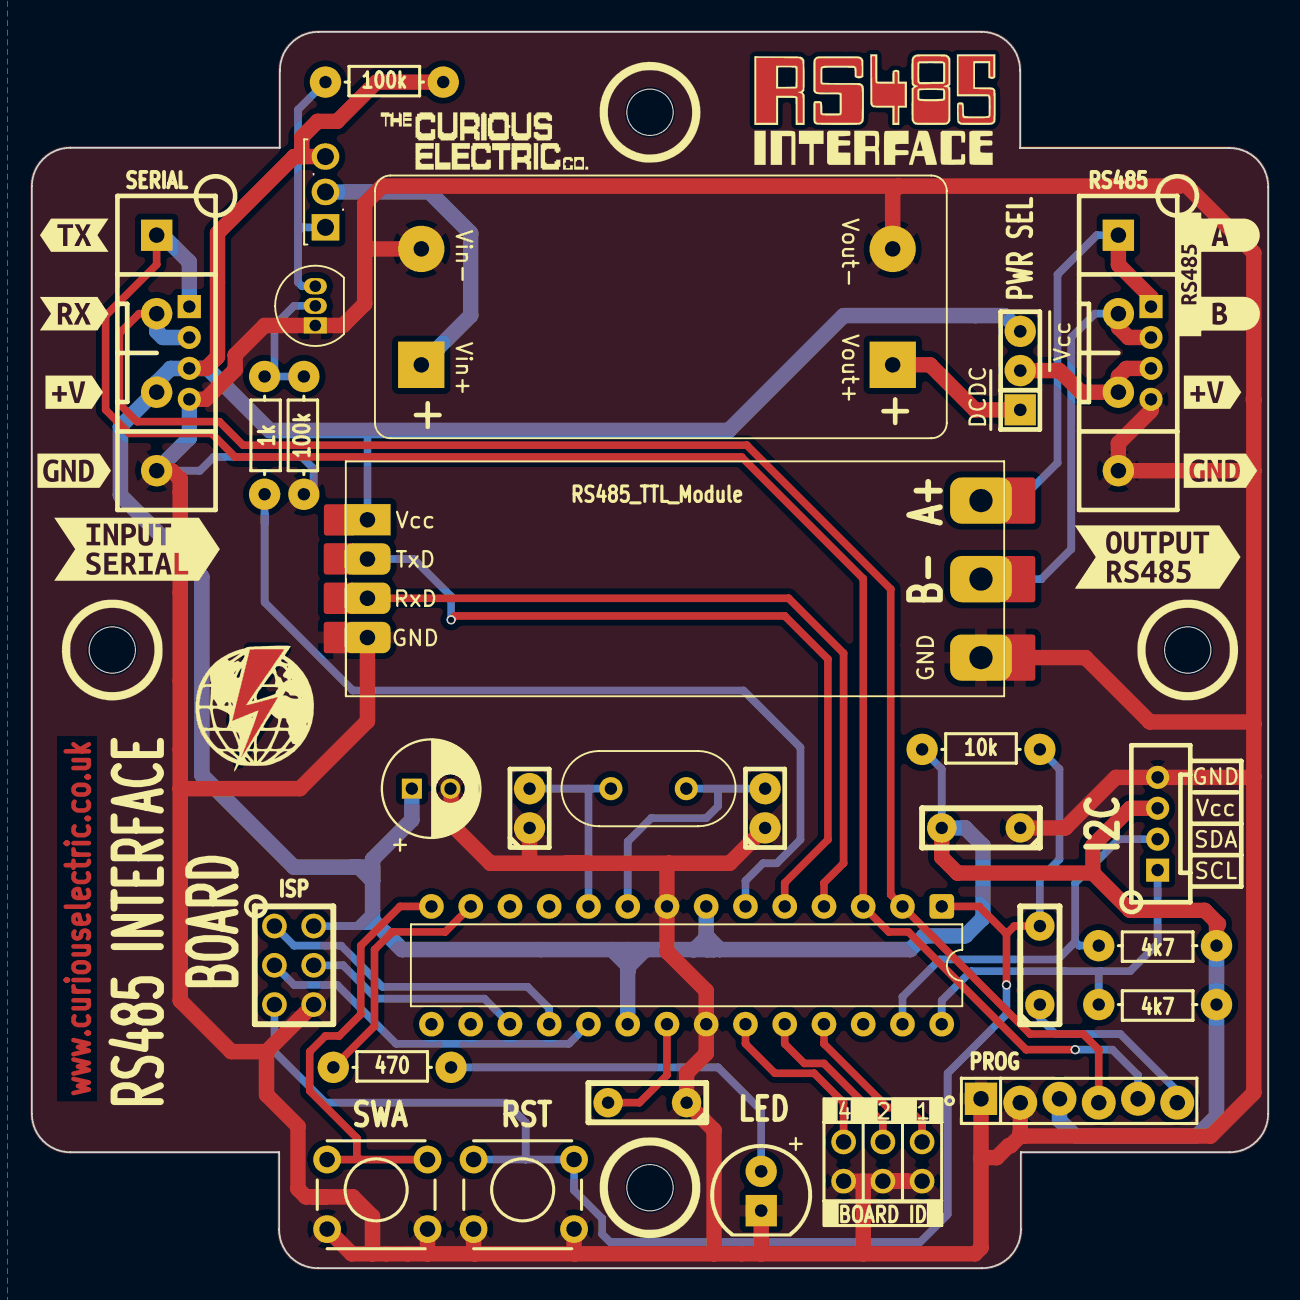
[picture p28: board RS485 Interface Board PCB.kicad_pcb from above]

Board: 2 copper layers, 80.0 x 80.0 mm, 44 parts (1 on the bottom side), 30 nets.

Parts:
C1, C3, C4: 100n; C1_wide_lg_pad_2
C2: 100u; C_Radial_D6.3_L11.2_P2.5
C5, C6: 22p; C1_lg_pad
D1: LED; TH_LED-5MM_AK
DCDC1: DC-DC_GENERIC; TH_DCDC_Step_up_MT3608
J1: PWR SEL; SIL-3_lg_pad_PWR_SELECT
P1: SERIAL; SIL-4_Grove_SCREW
P2: LOGO2; RS485 Logo Design
P3: PCB; PCB_outline_JSL22L
P5: I2C; SIL-4_Grove_Labelled_Correct
P6: RS485; SIL-4_Grove_SCREW
P7: BOARD ID; ID_SELECT_3x2
P8: PROG; TH_6x1_FTDI
P9: ISP; ISP_3x2
P10: LOGO3; TCEC_Words_13mm
P11: LOGO2; 2019_011_16_CuriousElectricCompany_Logo_Round_Logo_No_words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
Q1: 2N3904; TO-92_Inline
Q2: IRFR9220; TO-251-3_Vertical
R1: 1k; TH_Resistor_1
R2, R3: 100k; TH_Resistor_1
R4: 470; TH_Resistor_1
R5: 10k; TH_Resistor_1
R6, R7: 4k7; TH_Resistor_1
SW1: SWA; TH_FRONT_SW
SW2: RST; TH_FRONT_SW
U1: RS485_TTL_Module; TH_RS485_BI_SERIAL
U2: ATmega328P-P; DIP-28_W7.62mm
Y1: 8MHz_XTAL; Crystal_HC49-4H_Vertical
kibuzzard-68D6B9BB: G***; kibuzzard-68D6B9BB
kibuzzard-68D6B9C5: G***; kibuzzard-68D6B9C5
kibuzzard-68D6B99D: G***; kibuzzard-68D6B99D
kibuzzard-68D6B914: G***; kibuzzard-68D6B914
kibuzzard-68D6B946: G***; kibuzzard-68D6B946
kibuzzard-68D6B980: G***; kibuzzard-68D6B980
kibuzzard-68D6BA3C: G***; kibuzzard-68D6BA3C
kibuzzard-68D6BA4A: G***; kibuzzard-68D6BA4A
kibuzzard-68D6BA8E: G***; kibuzzard-68D6BA8E
kibuzzard-68D6BA98: G***; kibuzzard-68D6BA98
kibuzzard-68D6BAD1: G***; kibuzzard-68D6BAD1

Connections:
/ATMega328/A0: P7.5, U2.23 (PC0)
/ATMega328/A1: P7.3, U2.24 (PC1)
/ATMega328/A2: P7.1, U2.25 (PC2)
/ATMega328/D7: R4.1, U2.13 (PD7)
/ATMega328/D8: SW1.1, U2.14 (PB0)
/ATMega328/DTR: C4.1, P8.6
/ATMega328/MISO: P9.1, U2.18 (PB4)
/ATMega328/MOSI: P9.4, U2.17 (PB3)
/ATMega328/RESET: C4.2, P9.5, R5.2, SW2.1, U2.1 (~RESET/PC6)
/ATMega328/SCLK: P9.3, U2.19 (PB5)
/I2C_SCL: P5.1, R7.2, U2.28 (PC5)
/I2C_SDA: P5.2, R6.2, U2.27 (PC4)
/PWR_DC_DC: DCDC1.3 (+Vout), J1.1
/RS485_A: P6.1, U1.6 (A+)
/RS485_B: P6.2, U1.5 (B-)
/RS485_PWR: R1.2, U2.6 (PD4)
/RS485_Rx: U1.3 (Rx), U2.4 (PD2)
/RS485_Tx: U1.2 (Tx), U2.5 (PD3)
/Rx: P1.2, P8.4, U2.2 (PD0)
/Tx: P1.1, P8.5, U2.3 (PD1)
GND: C1.1, C2.2, C3.1, C5.1, C6.1, D1.1 (K), DCDC1.1 (-Vin), DCDC1.4 (-Vout), P1.4, P5.4, P6.4, P7.2, P7.4, P7.6, P8.1, P8.2, P9.6, Q1.1 (E), R2.1, SW1.2, SW2.2, U1.4 (GND), U2.8 (GND), U2.22 (GND)
unnamed: D1.2 (A), R4.2
unnamed: DCDC1.2 (+Vin), Q2.2 (D)
unnamed: J1.2, P6.3
unnamed: Q1.2 (B), R1.1, R2.2
unnamed: Q1.3 (C), Q2.1 (G), R3.1
unnamed: C1.2, U2.21 (AREF)
unnamed: C5.2, U2.9 (XTAL1/PB6), Y1.1
unnamed: C6.2, U2.10 (XTAL2/PB7), Y1.2
VCC: C2.1, C3.2, J1.3, P1.3, P5.3, P8.3, P9.2, Q2.3 (S), R3.2, R5.1, R6.1, R7.1, U1.1 (Vcc), U2.7 (VCC), U2.20 (AVCC)

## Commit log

2026-08-26 First update of PCB design
    [Hall_to_Freq.sch, RS485 Device Connector PCB.sch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]
2026-08-27 Added first version of instructions and PCB files
    Instructions not complete
    [RS485 Interface Board COmponent List.xlsx, RS485 Interface Board PCB.csv, RS485 Interface Board PCB.kicad_pcb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]
2026-08-28 added build instructions and PCB files
2026-08-28 Update RS485 Interface Board Instructions.odt
